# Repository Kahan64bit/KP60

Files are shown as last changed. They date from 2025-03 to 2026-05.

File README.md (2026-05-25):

# Custom 60% Keyboard PCB 

This is a custom-designed **60%** keyboard PCB created for mechanical keyboard enthusiasts who want full control over their build, layout, and firmware. The PCB is fully compatible with QMK/VIA and uses the QWERTY layout standard.

PCB dimensions have been made to fit [Tofu60 Redux Case](https://kbdfans.com/products/tofu60-redux-case?variant=42164599750795). More specification related information can be found below.

## Features

-  **QMK/VIA Compatible**
-  **USB-C Connector**
-  **Solder-Only Sockets**
-  **ESD Protection & Power Filtering**
-  **Standard 60% QWERTY Layout (ANSI support)**
-  **Overcurrent Protection**
-  **STM32 MCU**

## Specifications 

| Feature | Details |
|---|---|
| Microcontroller | STM32F072CBT6 |
| Connector | USB-C |
| Switch Compatibility | MX-style (5-pin support) |
| Firmware Support | QMK, VIA |
| Matrix | 5x14 (standard 60% matrix) |
| Dimensions | Standard 60% mounting holes |
| Auxiliary | ESD + Decoupling + Reset |
| Misc | 3V3 Regulator  |

## Schematic 
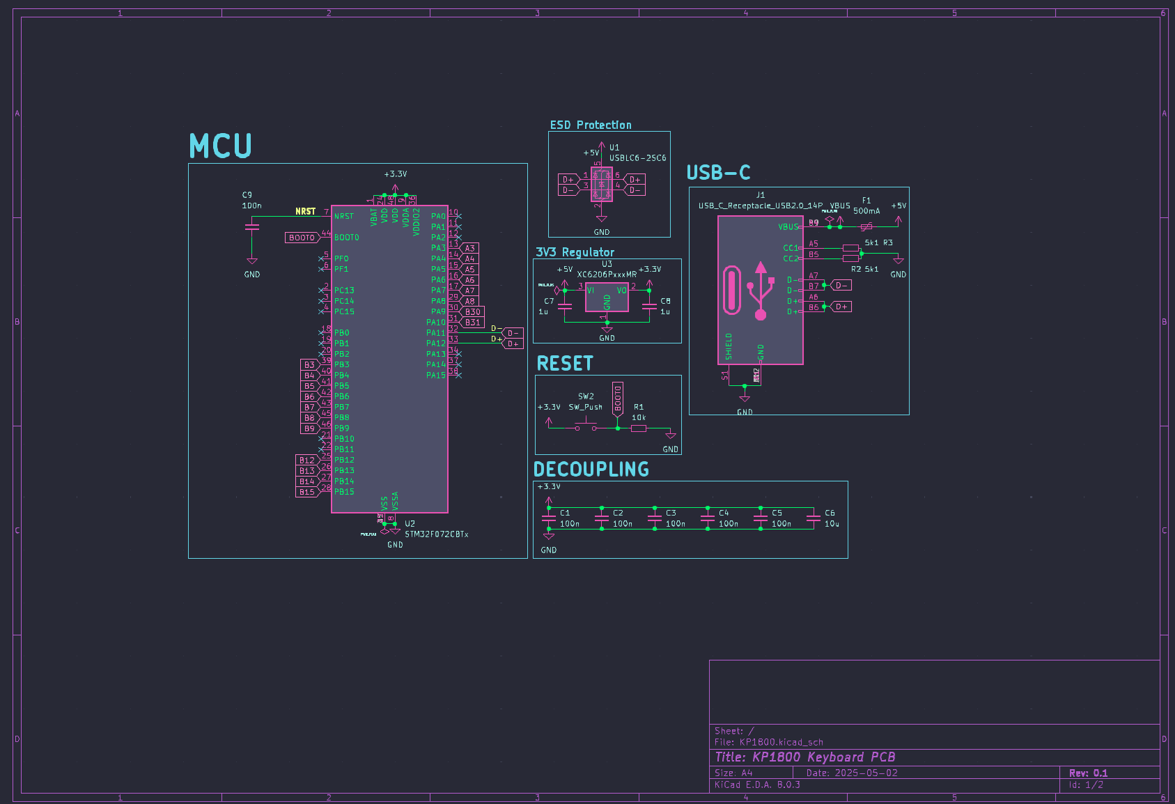
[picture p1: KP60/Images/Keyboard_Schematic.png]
Schematic


## Diode Matrix 
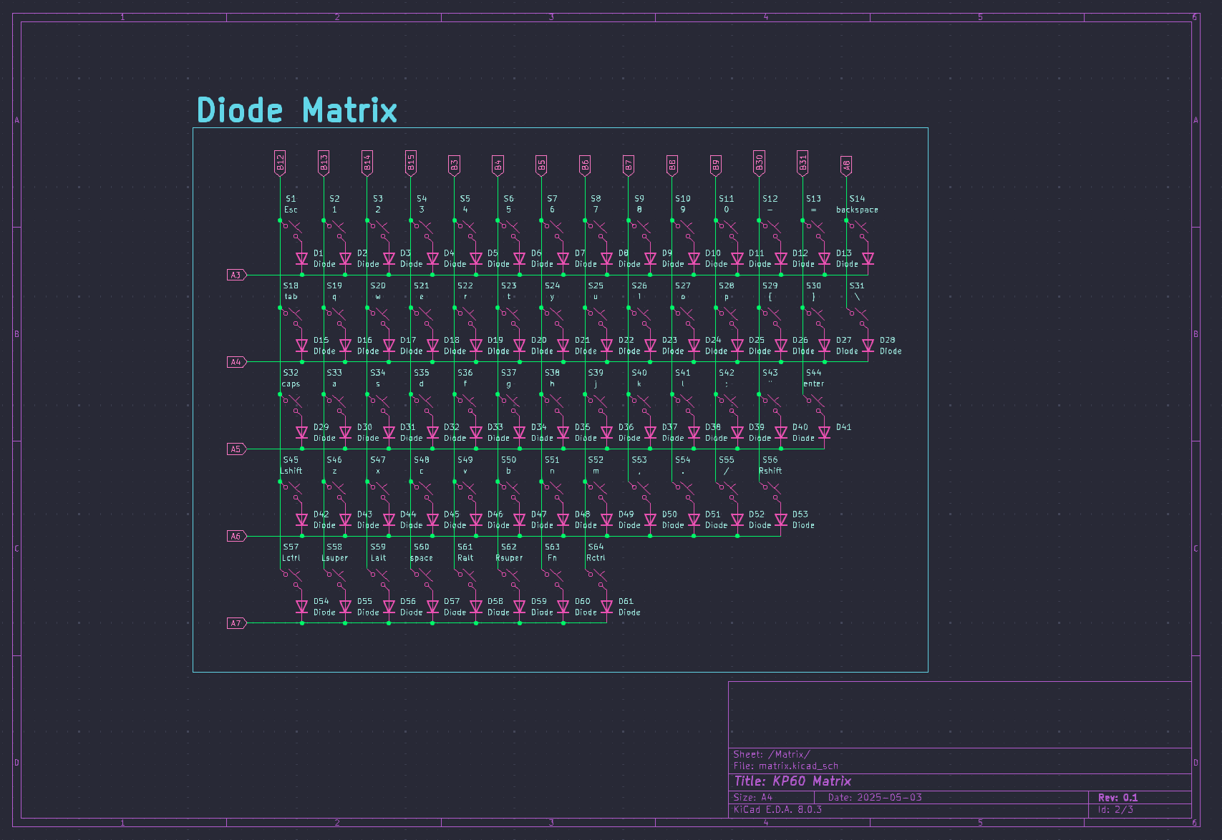
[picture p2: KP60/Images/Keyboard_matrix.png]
Matrix


## LED Matrix 
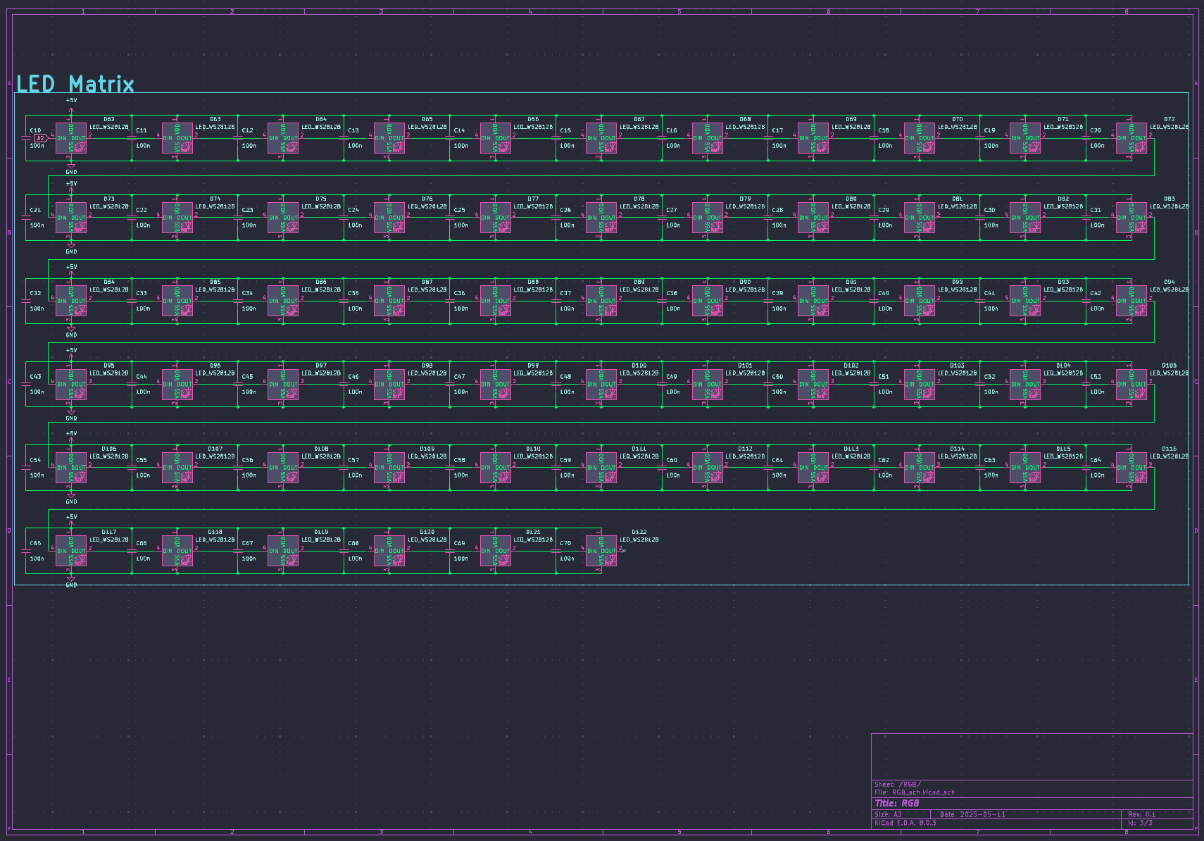
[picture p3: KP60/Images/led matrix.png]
LED


## PCB 
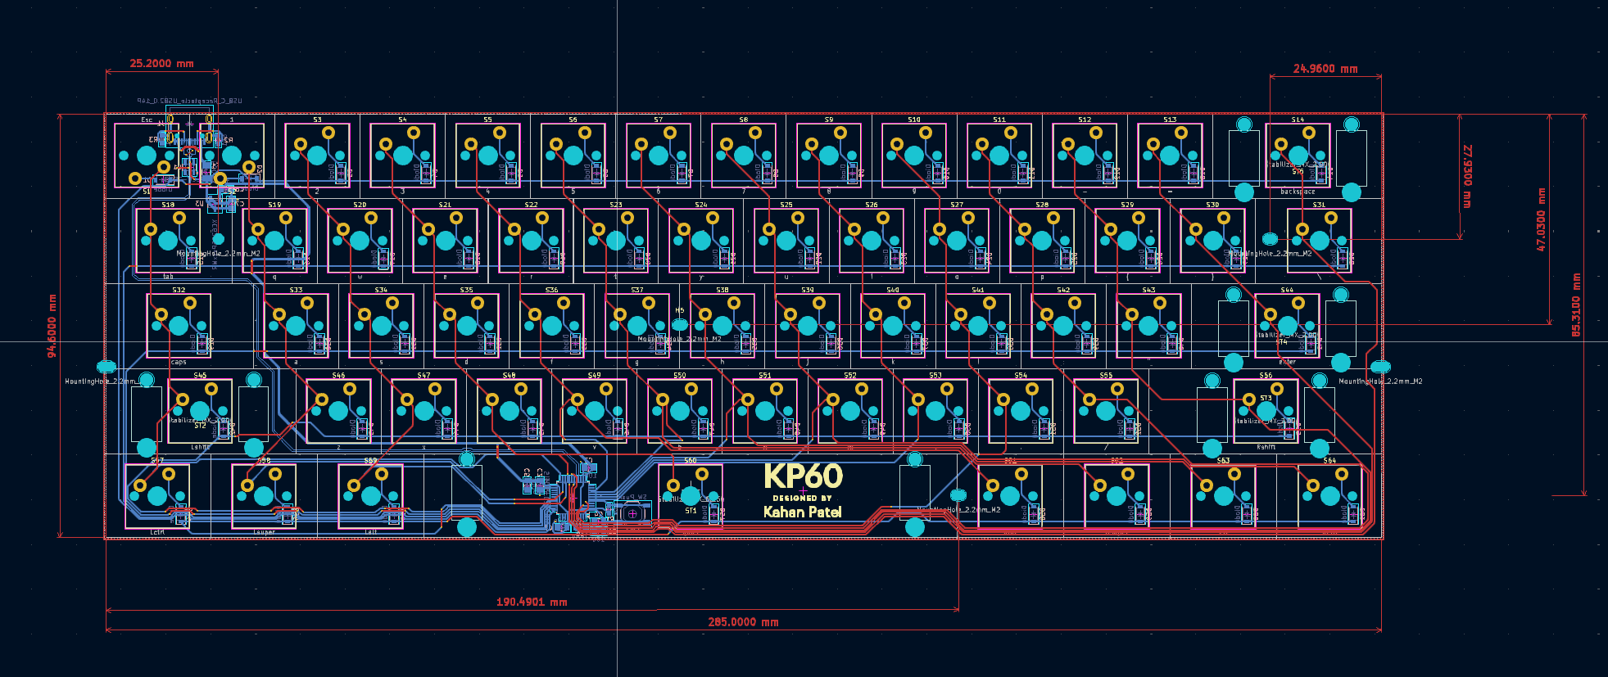
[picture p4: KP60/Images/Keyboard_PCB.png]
PCB


## Final Build
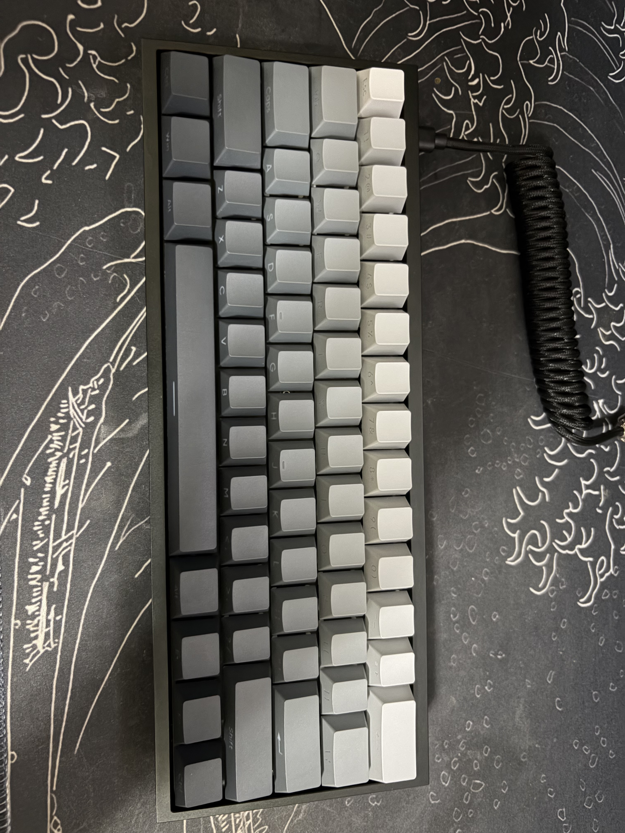
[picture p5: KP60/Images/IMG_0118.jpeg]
Build


## Render 
Click **[Render](https://github.com/Kahan64bit/KP60/blob/main/KP60/Images/PCB_Render.gif)** to see 3D Render

##  Roadmap  (Will be added as a seperate macroboard)

The KP60 project is actively evolving to support a broader range of features for keyboard customizers and enthusiasts. Here's a sneak peek at what’s coming in future versions:

### 🛠 Planned Features

-  **OLED Screen Integration**  
  Support for a 128x32 OLED screen for displaying layers, animations, or custom text.

-  **Hot-Swap Socket Support**  
  Enable easy switch swapping without soldering.

-  **Rotary Encoder Support**  
  Optional encoder support for volume, media, and custom actions.

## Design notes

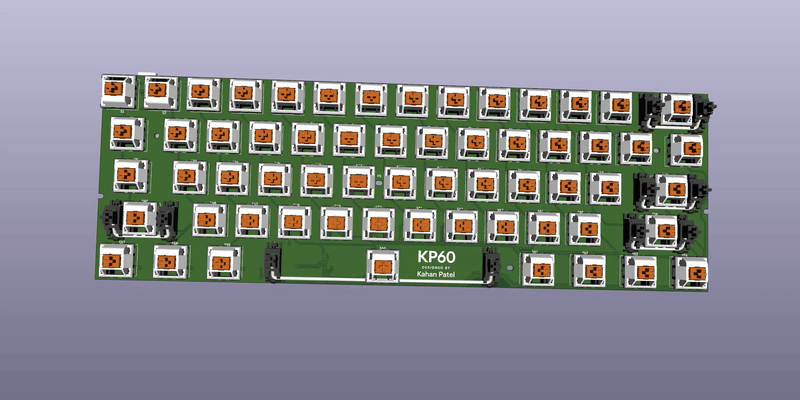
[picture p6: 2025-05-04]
KP60/Images/PCB_Render.gif

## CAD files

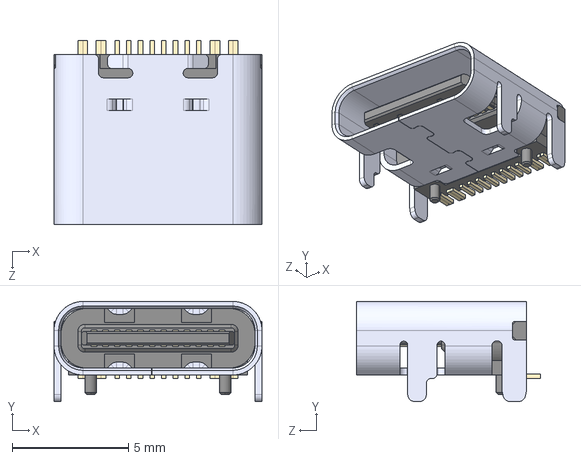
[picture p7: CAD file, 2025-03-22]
KP60/TYPE-C-31-M-12--3DModel-STEP-56544.STEP
8.94 x 4.30 x 7.90 mm

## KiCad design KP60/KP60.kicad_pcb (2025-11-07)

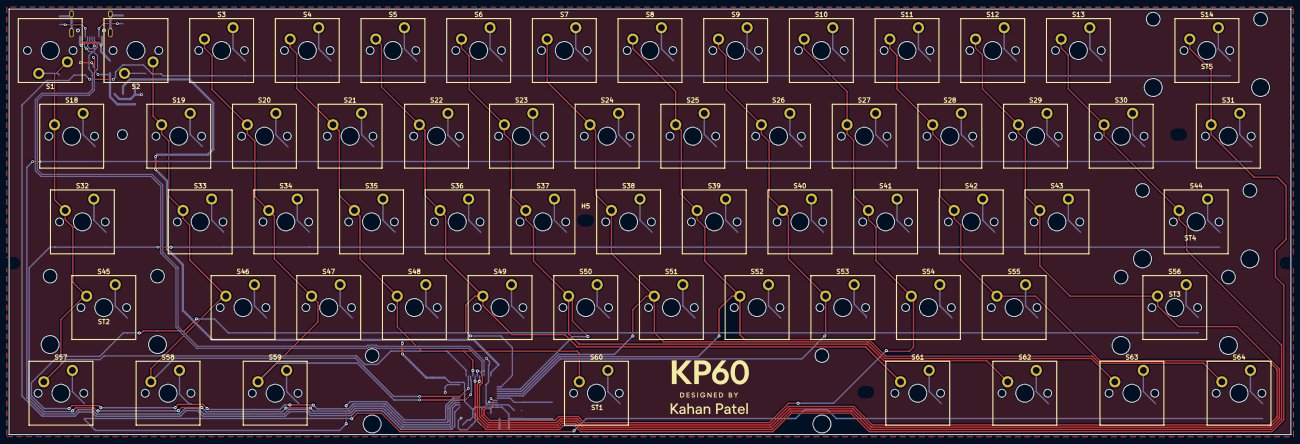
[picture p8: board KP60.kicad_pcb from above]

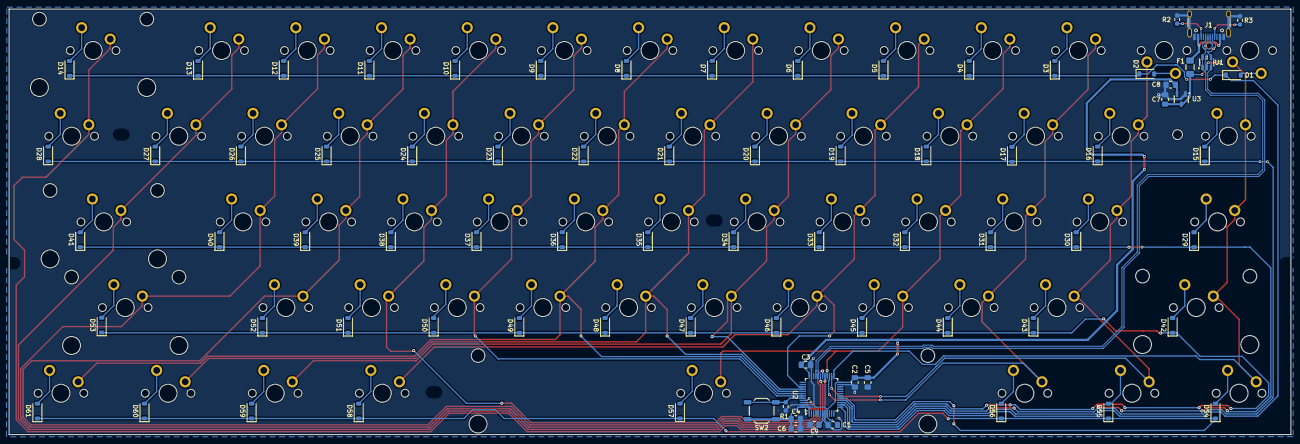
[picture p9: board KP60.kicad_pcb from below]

Board: 2 copper layers, 285.0 x 94.6 mm, 151 parts (79 on the bottom side), 90 nets.

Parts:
C1, C2, C3, C4, C5, C9: 100n; C_0805_2012Metric_Pad1.18x1.45mm_HandSolder
C6: 10u; C_0805_2012Metric_Pad1.18x1.45mm_HandSolder
C7, C8: 1u; C_0805_2012Metric_Pad1.18x1.45mm_HandSolder
D1, D2, D3, D4, D5, D6, D7, D8, D9, D10, D11, D12, D13, D14, D15, D16, D17, D18, D19, D20, D21, D22, D23, D24, D25, D26, D27, D28, D29, D30, D31, D32, D33, D34, D35, D36, D37, D38, D39, D40, D41, D42, D43, D44, D45, D46, D47, D48, D49, D50, D51, D52, D53, D54, D55, D56, D57, D58, D59, D60, D61: Diode; D_SOD-123
F1: 500mA; Fuse_1206_3216Metric_Pad1.42x1.75mm_HandSolder
H1, H2, H3, H4, H5, H6: MountingHole_2.2mm_M2
J1: USB_C_Receptacle_USB2.0_14P; USB_C_Receptacle_HRO_TYPE-C-31-M-12
R1: 10k; R_0603_1608Metric_Pad0.98x0.95mm_HandSolder
R2, R3: 5k1; R_0603_1608Metric_Pad0.98x0.95mm_HandSolder
S1: Esc; MX_PCB_1.00u
S2: 1; MX_PCB_1.00u
S3: 2; MX_PCB_1.00u
S4: 3; MX_PCB_1.00u
S5: 4; MX_PCB_1.00u
S6: 5; MX_PCB_1.00u
S7: 6; MX_PCB_1.00u
S8: 7; MX_PCB_1.00u
S9: 8; MX_PCB_1.00u
S10: 9; MX_PCB_1.00u
S11: 0; MX_PCB_1.00u
S12: -; MX_PCB_1.00u
S13: =; MX_PCB_1.00u
S14: backspace; MX_PCB_2.00u
S18: tab; MX_PCB_1.50u
S19: q; MX_PCB_1.00u
S20: w; MX_PCB_1.00u
S21: e; MX_PCB_1.00u
S22: r; MX_PCB_1.00u
S23: t; MX_PCB_1.00u
S24: y; MX_PCB_1.00u
S25: u; MX_PCB_1.00u
S26: i; MX_PCB_1.00u
S27: o; MX_PCB_1.00u
S28: p; MX_PCB_1.00u
S29: {; MX_PCB_1.00u
S30: }; MX_PCB_1.00u
S31: \; MX_PCB_1.50u
S32: caps; MX_PCB_1.75u
S33: a; MX_PCB_1.00u
S34: s; MX_PCB_1.00u
S35: d; MX_PCB_1.00u
S36: f; MX_PCB_1.00u
S37: g; MX_PCB_1.00u
S38: h; MX_PCB_1.00u
S39: j; MX_PCB_1.00u
S40: k; MX_PCB_1.00u
S41: l; MX_PCB_1.00u
S42: ;; MX_PCB_1.00u
S43: "; MX_PCB_1.00u
S44: enter; MX_PCB_2.25u
S45: Lshift; MX_PCB_2.25u
S46: z; MX_PCB_1.00u
S47: x; MX_PCB_1.00u
S48: c; MX_PCB_1.00u
S49: v; MX_PCB_1.00u
S50: b; MX_PCB_1.00u
S51: n; MX_PCB_1.00u
S52: m; MX_PCB_1.00u
S53: ,; MX_PCB_1.00u
S54: .; MX_PCB_1.00u
S55: /; MX_PCB_1.00u
S56: Rshift; MX_PCB_2.75u
S57: Lctrl; MX_PCB_1.25u
S58: Lsuper; MX_PCB_1.25u
S59: Lalt; MX_PCB_1.25u
S60: space; MX_PCB_6.25u
S61: Ralt; MX_PCB_1.25u
S62: Rsuper; MX_PCB_1.25u
S63: Fn; MX_PCB_1.25u
S64: Rctrl; MX_PCB_1.25u
ST1: Stabilizer_MX_6.25u
ST2, ST3, ST4, ST5: Stabilizer_MX_2.00u
SW2: SW_Push; SW_SPST_TL3342
U1: USBLC6-2SC6; SOT-23-6
U2: STM32F072CBTx; LQFP-48_7x7mm_P0.5mm
U3: XC6206PxxxMR; SOT-23-3

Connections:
+3.3V: C1.1, C2.1, C3.1, C4.1, C5.1, C6.1, C8.1, SW2.1, U2.1 (VBAT), U2.9 (VDDA), U2.24 (VDD), U2.36 (VDDIO2), U2.48 (VDD), U3.2 (VO)
+5V: C7.1, F1.2, U1.5 (VBUS), U3.3 (VI)
/NRST: C9.2, U2.7 (NRST)
A3: D1.1 (K), D2.1 (K), D3.1 (K), D4.1 (K), D5.1 (K), D6.1 (K), D7.1 (K), D8.1 (K), D9.1 (K), D10.1 (K), D11.1 (K), D12.1 (K), D13.1 (K), D14.1 (K), U2.13 (PA3)
A4: D15.1 (K), D16.1 (K), D17.1 (K), D18.1 (K), D19.1 (K), D20.1 (K), D21.1 (K), D22.1 (K), D23.1 (K), D24.1 (K), D25.1 (K), D26.1 (K), D27.1 (K), D28.1 (K), U2.14 (PA4)
A5: D29.1 (K), D30.1 (K), D31.1 (K), D32.1 (K), D33.1 (K), D34.1 (K), D35.1 (K), D36.1 (K), D37.1 (K), D38.1 (K), D39.1 (K), D40.1 (K), D41.1 (K), U2.15 (PA5)
A6: D42.1 (K), D43.1 (K), D44.1 (K), D45.1 (K), D46.1 (K), D47.1 (K), D48.1 (K), D49.1 (K), D50.1 (K), D51.1 (K), D52.1 (K), D53.1 (K), U2.16 (PA6)
A7: D54.1 (K), D55.1 (K), D56.1 (K), D57.1 (K), D58.1 (K), D59.1 (K), D60.1 (K), D61.1 (K), U2.17 (PA7)
A8: S14.1, S31.1, U2.29 (PA8)
B3: S5.1, S22.1, S36.1, S49.1, S61.1, U2.39 (PB3)
B4: S6.1, S23.1, S37.1, S50.1, S62.1, U2.40 (PB4)
B5: S7.1, S24.1, S38.1, S51.1, S63.1, U2.41 (PB5)
B6: S8.1, S25.1, S39.1, S52.1, S64.1, U2.42 (PB6)
B7: S9.1, S26.1, S40.1, S53.1, U2.43 (PB7)
B8: S10.1, S27.1, S41.1, S54.1, U2.45 (PB8)
B9: S11.1, S28.1, S42.1, S55.1, U2.46 (PB9)
B12: S1.1, S18.1, S32.1, S45.1, S57.1, U2.25 (PB12)
B13: S2.1, S19.1, S33.1, S46.1, S58.1, U2.26 (PB13)
B14: S3.1, S20.1, S34.1, S47.1, S59.1, U2.27 (PB14)
B15: S4.1, S21.1, S35.1, S48.1, S60.1, U2.28 (PB15)
B30: S12.1, S29.1, S43.1, S56.1, U2.30 (PA9)
B31: S13.1, S30.1, S44.1, U2.31 (PA10)
BOOT0: R1.1, SW2.2, U2.44 (BOOT0)
D+: J1.A6 (D+), J1.B6 (D+), U1.1 (I/O1), U1.6 (I/O1), U2.33 (PA12)
D-: J1.A7 (D-), J1.B7 (D-), U1.3 (I/O2), U1.4 (I/O2), U2.32 (PA11)
GND: C1.2, C2.2, C3.2, C4.2, C5.2, C6.2, C7.2, C8.2, C9.1, J1.A1 (GND), J1.A12 (GND), J1.B1 (GND), J1.B12 (GND), J1.S1 (SHIELD), R1.2, R2.1, R3.1, U1.2 (GND), U2.8 (VSSA), U2.23 (VSS), U2.35 (VSS), U2.47 (VSS), U3.1 (GND)
unnamed: D1.2 (A), S1.2
unnamed: D2.2 (A), S2.2
unnamed: D3.2 (A), S3.2
unnamed: D4.2 (A), S4.2
unnamed: D5.2 (A), S5.2
unnamed: D6.2 (A), S6.2
unnamed: D7.2 (A), S7.2
unnamed: D8.2 (A), S8.2
unnamed: D9.2 (A), S9.2
unnamed: D10.2 (A), S10.2
unnamed: D11.2 (A), S11.2
unnamed: D12.2 (A), S12.2
unnamed: D13.2 (A), S13.2
unnamed: D14.2 (A), S14.2
unnamed: D15.2 (A), S18.2
unnamed: D16.2 (A), S19.2
unnamed: D17.2 (A), S20.2
unnamed: D18.2 (A), S21.2
unnamed: D19.2 (A), S22.2
unnamed: D20.2 (A), S23.2
unnamed: D21.2 (A), S24.2
unnamed: D22.2 (A), S25.2
unnamed: D23.2 (A), S26.2
unnamed: D24.2 (A), S27.2
unnamed: D25.2 (A), S28.2
unnamed: D26.2 (A), S29.2
unnamed: D27.2 (A), S30.2
unnamed: D28.2 (A), S31.2
unnamed: D29.2 (A), S32.2
unnamed: D30.2 (A), S33.2
unnamed: D31.2 (A), S34.2
unnamed: D32.2 (A), S35.2
unnamed: D33.2 (A), S36.2
unnamed: D34.2 (A), S37.2
unnamed: D35.2 (A), S38.2
unnamed: D36.2 (A), S39.2
unnamed: D37.2 (A), S40.2
unnamed: D38.2 (A), S41.2
unnamed: D39.2 (A), S42.2
unnamed: D40.2 (A), S43.2
unnamed: D41.2 (A), S44.2
unnamed: D42.2 (A), S45.2
unnamed: D43.2 (A), S46.2
unnamed: D44.2 (A), S47.2
unnamed: D45.2 (A), S48.2
unnamed: D46.2 (A), S49.2
unnamed: D47.2 (A), S50.2
unnamed: D48.2 (A), S51.2
unnamed: D49.2 (A), S52.2
unnamed: D50.2 (A), S53.2
unnamed: D51.2 (A), S54.2
unnamed: D52.2 (A), S55.2
unnamed: D53.2 (A), S56.2
unnamed: D54.2 (A), S57.2
unnamed: D55.2 (A), S58.2
unnamed: D56.2 (A), S59.2
unnamed: D57.2 (A), S60.2
unnamed: D58.2 (A), S61.2
unnamed: D59.2 (A), S62.2
unnamed: D60.2 (A), S63.2
unnamed: D61.2 (A), S64.2
unnamed: J1.A5 (CC1), R3.2
unnamed: J1.B5 (CC2), R2.2
VBUS: F1.1, J1.A4 (VBUS), J1.A9 (VBUS), J1.B4 (VBUS), J1.B9 (VBUS)

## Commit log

2025-03-18 Added Footprints + Symbols
    [KP1800.kicad_pcb, KP1800.kicad_sch]
2025-03-19 Completed MCU Circuit and USB Circuit
    [KP1800.kicad_sch]
2025-03-19 Passed Electric Rules Check // Will work on cleaning up schematic then beginning PCB design
2025-03-19 Formatted Matrix
    [KP1800.kicad_sch, matrix.kicad_sch]
2025-03-21 Working on PCB // Laid out key switches // 60% board
    [KP1800.kicad_sch, matrix.kicad_sch]
2025-03-21 Cleaned up rats nest
    [KP1800.kicad_pcb]
2025-03-22 Added traces to matrix
    [KP1800.kicad_sch, TYPE-C-31-M-12--3DModel-STEP-56544.STEP]
2025-03-23 Added mounting moles + stabilizers WIP
    [KP1800.kicad_pcb]
2025-03-24 80% of signal traces are complete
    [KP1800.kicad_pcb]
2025-03-30 All traces done. Now working on grounding.
    [KP1800.kicad_sch, matrix.kicad_sch]
2025-03-30 Optimized Traces + Fixed Silkscreen DRC Errors
2025-04-07 Added Ground Filled Zones + Finished All Traces // Working on final touches
    [KP1800.kicad_pcb]
2025-04-08 Adding silkscreen + polish
    [KP1800.kicad_pcb]
2025-04-08 Polishing Cont.
    [KP1800.kicad_pcb]
2025-05-02 Revisional Changes
    [KP1800.kicad_sch, matrix.kicad_sch]
2025-05-02 add measurements + pictures
    [KP1800.kicad_pcb]
2025-05-04 upload design images for readme
    [KP1800.kicad_pcb, KP1800.kicad_sch, TYPE-C-31-M-12--3DModel-STEP-56544.STEP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]
2025-05-04 more images + naming fixes
    [KP60.kicad_pcb, KP60.kicad_sch, matrix.kicad_sch]
2025-05-11 add led matrix circuit + passed ERC
    [KP60.kicad_sch, RGB_sch.kicad_sch]
2025-05-11 generated gerbers
    [KP60-B_Cu.gbl, KP60-B_Mask.gbs, KP60-B_Paste.gbp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]
2025-06-03 Formatting Changes
    [KP60.kicad_pcb, KP60.kicad_sch, RGB_sch.kicad_sch]
2025-11-07 Mechanical Changes
    [KP60-B_Cu.gbl, KP60-B_Mask.gbs, KP60-B_Paste.gbp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]
2025-11-07 diff. trace tweaks
    [KP60.kicad_pcb, KP60.kicad_sch]
